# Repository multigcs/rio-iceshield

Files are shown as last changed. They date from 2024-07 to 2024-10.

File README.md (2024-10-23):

# rio-iceshield
6 Axis LinuxCNC-RIO Raspberry-PI FPGA-Hat - kicad project

**experimental**

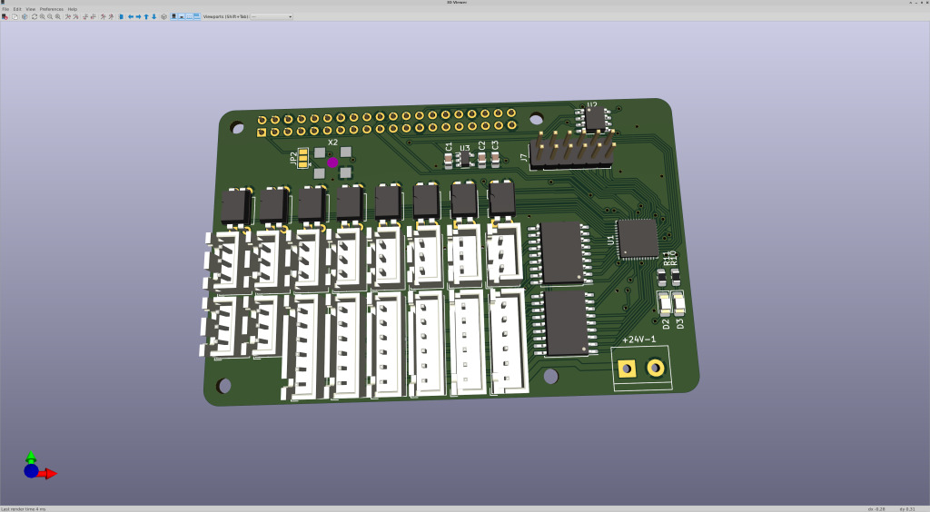
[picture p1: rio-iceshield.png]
rio-iceshield


## software / gateware
https://github.com/multigcs/riocore

## BOM

## Forum
German: https://www.cnc-aus-holz.at/index.php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
English: https://forum.linuxcnc.org/18-computer/49142-linuxcnc-rio-realtimeio-for-linuxcnc-based-on-fpga-ice40-ecp5

## to provide a clock signal for the FPGA
```
gpio mode 7 clock
gpio clock 7 5000000
```

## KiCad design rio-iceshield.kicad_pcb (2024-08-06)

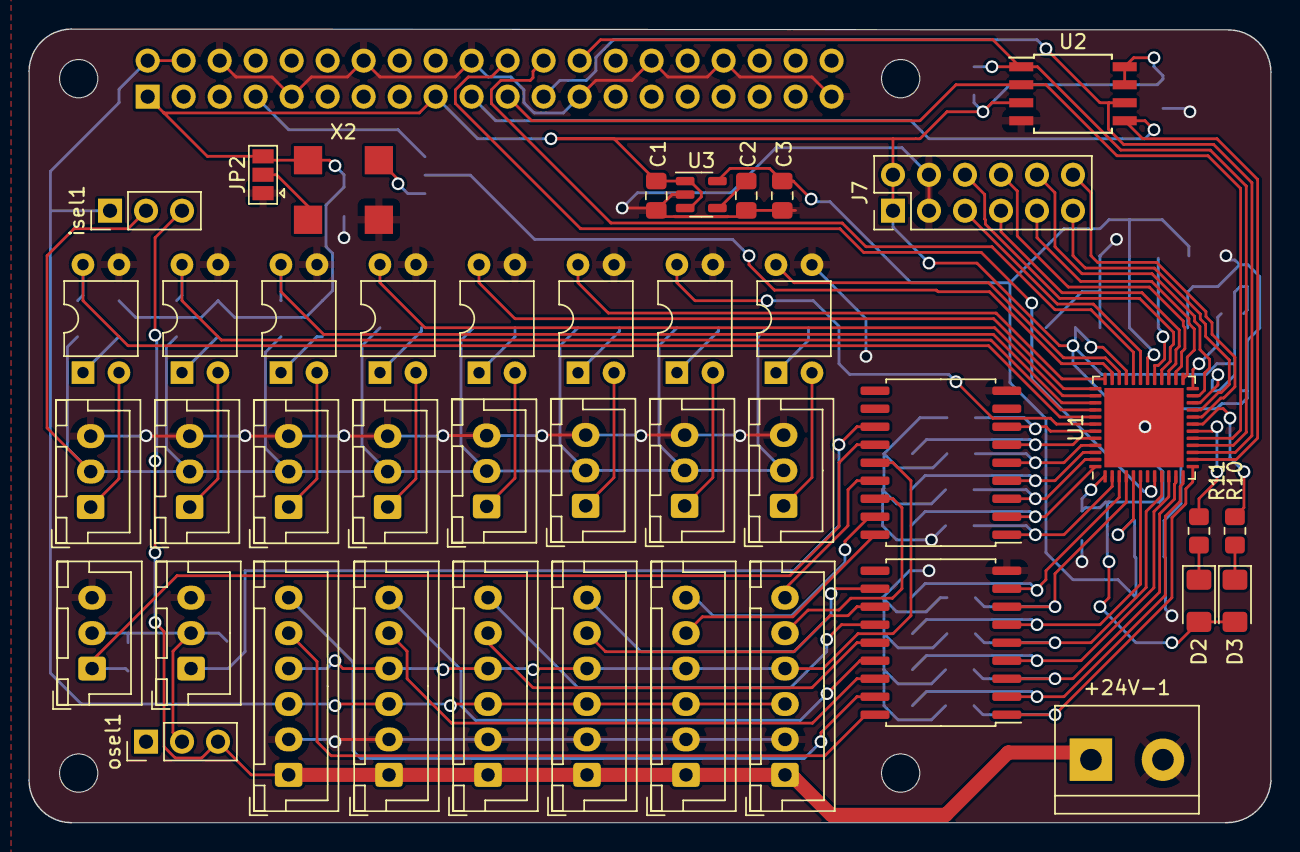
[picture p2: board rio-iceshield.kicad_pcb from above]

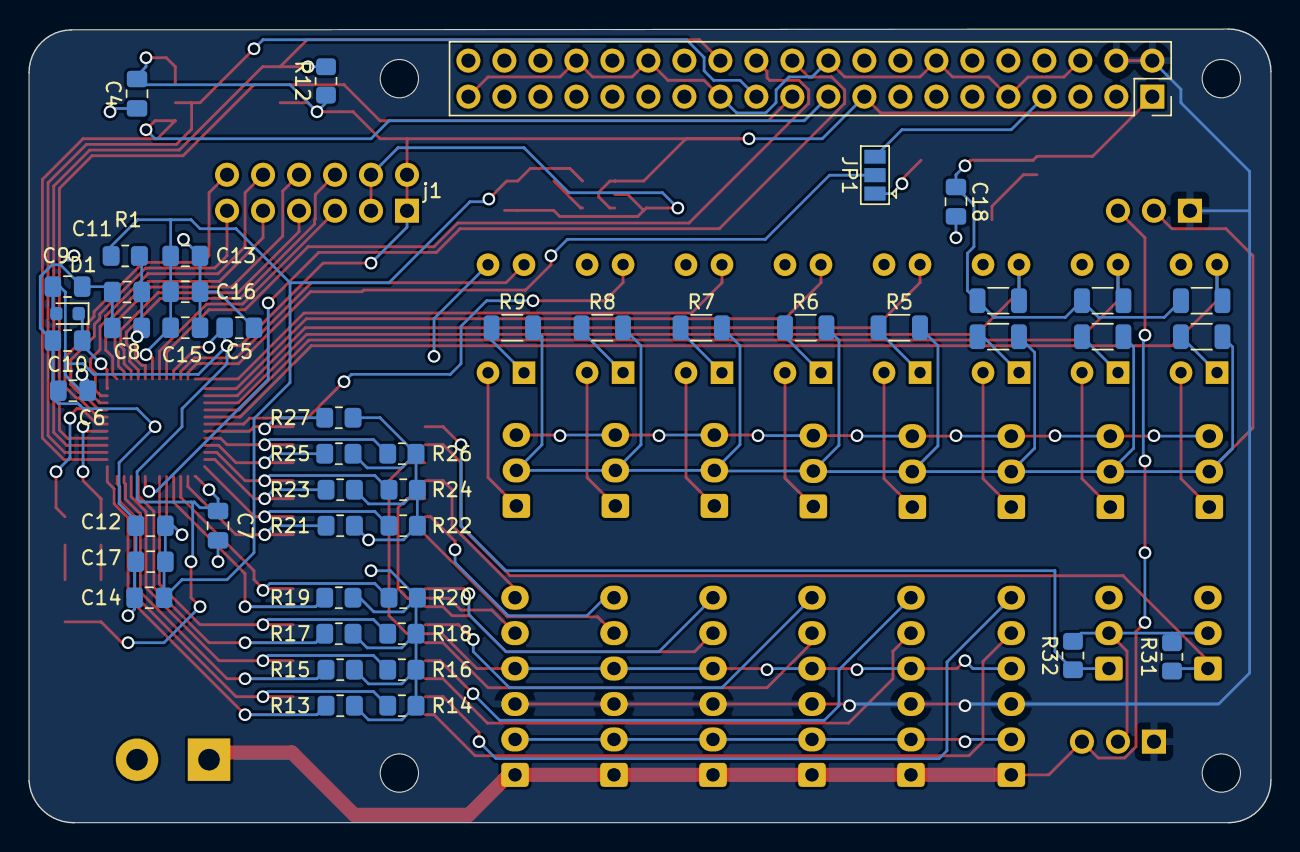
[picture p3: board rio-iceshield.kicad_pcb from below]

Board: 2 copper layers, 87.6 x 56.0 mm, 94 parts (48 on the bottom side), 86 nets.

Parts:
+24V-1: Screw_Terminal_01x02; TerminalBlock_bornier-2_P5.08mm
C1, C3: 4u7; C_0805_2012Metric_Pad1.18x1.45mm_HandSolder
C2, C13, C17: 10n; C_0805_2012Metric_Pad1.18x1.45mm_HandSolder
C4, C5, C6, C7, C8, C9, C10, C14, C16, C18: 100n; C_0805_2012Metric_Pad1.18x1.45mm_HandSolder
C11: 10u; C_0805_2012Metric_Pad1.18x1.45mm_HandSolder
C12, C15: 1u; C_0805_2012Metric_Pad1.18x1.45mm_HandSolder
D1: 1N 4148WT7 DII; D_0603_1608Metric
D2, D3: LED; LED_1206_3216Metric_Pad1.42x1.75mm_HandSolder
J2, J3, J4, J5, J6: Conn_01x06; JST_XH_B6B-XH-A_1x06_P2.50mm_Vertical
J7: Conn_02x06_Odd_Even; PinHeader_2x06_P2.54mm_Vertical
JP1, JP2: SolderJumper_3_Open; SolderJumper-3_P1.3mm_Open_Pad1.0x1.5mm
Jo1: Conn_01x06; JST_XH_B6B-XH-A_1x06_P2.50mm_Vertical
MH1, MH2, MH3, MH4: MountingHole_2.7mm_M2.5
R1: 100; R_0805_2012Metric_Pad1.20x1.40mm_HandSolder
R2, R3, R4, R5, R6, R7, R8, R9: 3K3; R_1206_3216Metric
R10, R11: 900; R_0805_2012Metric_Pad1.20x1.40mm_HandSolder
R12: 10k; R_0805_2012Metric_Pad1.20x1.40mm_HandSolder
R13, R14, R15, R16, R17, R18, R19, R20, R21, R22, R23, R24, R25, R26, R27: 20k; R_0805_2012Metric_Pad1.20x1.40mm_HandSolder
R28, R29, R30: 20K; R_1206_3216Metric
R31, R32: 3k3; R_0805_2012Metric_Pad1.20x1.40mm_HandSolder
U1: ICE40UP5K-SG48ITR; QFN-48-1EP_7x7mm_P0.5mm_EP5.6x5.6mm
U2: AT25SF041B-SHD 4 Mb; SOIC-8W_5.3x5.3mm_P1.27mm
U3: LD3985M122R_SOT23; SOT-23-5
U4, U5: ULN2803A; SOIC-18W_7.5x11.6mm_P1.27mm
U7, U8, U9, U10, U11, U12, U13, U14: PC817; DIP-4_W7.62mm
X2: XO91; Oscillator_SMD_EuroQuartz_XO91-4Pin_7.0x5.0mm
input1, input2, input3, input4, input5, input6, input7, input8: Conn_01x03; JST_XH_B3B-XH-A_1x03_P2.50mm_Vertical
isel1: Conn_01x03; PinHeader_1x03_P2.54mm_Vertical
j1: GPIO; PinSocket_2x20_P2.54mm_Vertical
osel1: Conn_01x03; PinHeader_1x03_P2.54mm_Vertical
output1, output2: Conn_01x03; JST_XH_B3B-XH-A_1x03_P2.50mm_Vertical

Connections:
1v2: C3.1, C12.1, C13.1, C14.1, C15.1, C16.1, C17.1, R1.1, U1.5 (VCC), U1.30 (VCC), U3.5 (VOUT)
2: R21.2, U1.2 (IOB_6a), U5.1 (I1)
2v5: C10.1, D1.1 (K), U1.24 (VPP_2V5)
3: R20.2, U1.3 (IOB_9b), U4.8 (I8)
3v3: C1.1, C4.2, C5.2, C6.2, C7.2, C9.1, C18.1, D1.2 (A), D2.2 (A), D3.2 (A), J7.1, J7.2, JP2.3 (B), R12.1, R28.1, R29.1, R30.1, U1.1 (VCCIO_2), U1.22 (SPI_VCCIO1), U1.33 (VCCIO_0), U2.3 (~WP/IO2), U2.7 (~HOLD/IO3), U2.8 (VCC), U3.1 (VIN), U3.3 (INH), X2.4 (V+), j1.1, j1.17
4: R19.2, U1.4 (IOB_8a), U4.7 (I7)
5v: J2.3, J3.3, J4.3, J5.3, J6.3, Jo1.3, isel1.1, j1.2, j1.4, osel1.1
6: R18.2, U1.6 (IOB_13b), U4.6 (I6)
9: R17.2, U1.9 (IOB_16a), U4.5 (I5)
10: R16.2, U1.10 (IOB_18a), U4.4 (I4)
11: R15.2, U1.11 (IOB_20a), U4.3 (I3)
12: R14.2, U1.12 (IOB_22a), U4.2 (I2)
12v: +24V-1.1, J2.1, J3.1, J4.1, J5.1, J6.1, Jo1.1, isel1.3, osel1.3
13: R13.2, U1.13 (IOB_24a), U4.1 (I1)
18: R11.1, U1.18 (IOB_31b)
19: R10.1, U1.19 (IOB_29b)
20: J7.12, U1.20 (IOB_25b_G3)
21: J7.11, U1.21 (IOB_23b)
23: J7.10, U1.23 (IOT_37a)
25: J7.9, U1.25 (IOT_36b)
26: J7.8, U1.26 (IOT_39a)
27: J7.7, U1.27 (IOT_38b)
28: J7.6, U1.28 (IOT_41a)
31: J7.5, U1.31 (IOT_42b)
32: U1.32 (IOT_43a), j1.24
34: U1.34 (IOT_44b), U14.4
35: JP1.2 (C), U1.35 (IOT_46b_G0)
36: U1.36 (IOT_48b), U12.4
37: U1.37 (IOT_45a_G1), U11.4
38: U1.38 (IOT_50b), U10.4
39: R28.2, U1.39 (RGB0), U9.4
40: R29.2, U1.40 (RGB1), U8.4
41: R30.2, U1.41 (RGB2), U7.4
42: U1.42 (IOT_51a), U13.4
43: R27.2, U1.43 (IOT_49a), U5.7 (I7)
44: R26.2, U1.44 (IOB_3b_G6), U5.6 (I6)
45: R25.2, U1.45 (IOB_5b), U5.5 (I5)
46: R24.2, U1.46 (IOB_0a), U5.4 (I4)
47: R23.2, U1.47 (IOB_2a), U5.3 (I3)
48: R22.2, U1.48 (IOB_4a), U5.2 (I2)
CRESET: U1.8 (~CRESET), j1.22
unnamed: D2.1 (K), R11.2
unnamed: D3.1 (K), R10.2
unnamed: JP1.1 (A), X2.3 (OUT)
unnamed: JP2.2 (C), X2.1 (EN)
unnamed: R2.1, U7.1
unnamed: R3.1, U8.1
unnamed: R4.1, U9.1
unnamed: R5.1, U10.1
unnamed: R6.1, U11.1
unnamed: R7.1, U12.1
unnamed: R8.1, U13.1
unnamed: R9.1, U14.1
unnamed: C8.1, C11.1, R1.2, U1.29 (VCCPLL)
unnamed: C2.1, U3.4 (BYP)
unnamed: U7.2, input1.1
unnamed: U8.2, input2.1
unnamed: U9.2, input3.1
unnamed: U10.2, input4.1
unnamed: U11.2, input5.1
unnamed: U12.2, input6.1
unnamed: U13.2, input7.1
unnamed: U14.2, input8.1
RPI_CLK: JP1.3 (B), j1.7
SPI_CS1: R12.2, U1.16 (IOB_35b_SPI_SS), U2.1 (~CS), j1.26
SPI_MISO: U1.17 (IOB_33b_SPI_SI), U2.2 (SO/IO1), j1.21
SPI_MOSI: U1.14 (IOB_32a_SPI_SO), U2.5 (SI/IO0), j1.19
SPI_SCK: U1.15 (IOB_34a_SPI_SCK), U2.6 (SCK), j1.23
enable: J2.4, J3.4, J4.4, J5.4, J6.4, Jo1.4, U5.14 (O5)
gnd: +24V-1.2, C1.2, C2.2, C3.2, C4.1, C5.1, C6.1, C7.1, C8.2, C9.2, C10.2, C11.2, C12.2, C13.2, C14.2, C15.2, C16.2, C17.2, C18.2, J2.2, J3.2, J4.2, J5.2, J6.2, J7.3, J7.4, JP2.1 (A), Jo1.2, R13.1, R14.1, R15.1, R16.1, R17.1, R18.1, R19.1, R20.1, R21.1, R22.1, R23.1, R24.1, R25.1, R26.1, R27.1, U1.49 (GND), U2.4 (GND), U3.2 (GND), U4.9 (GND), U5.9 (GND), U7.3, U8.3, U9.3, U10.3, U11.3, U12.3, U13.3, U14.3, X2.2 (GND), input1.3, input2.3, input3.3, input4.3, input5.3, input6.3, input7.3, input8.3, j1.6, j1.9, j1.14, j1.20, j1.25, j1.30, j1.34, j1.39, output1.3, output2.3
in_power: R2.2, R3.2, R4.2, R5.2, R6.2, R7.2, R8.2, R9.2, input1.2, input2.2, input3.2, input4.2, input5.2, input6.2, input7.2, input8.2, isel1.2
j1_dir: Jo1.6, U4.17 (O2)
j1_step: Jo1.5, U4.18 (O1)
j2_dir: J2.6, U4.15 (O4)
j2_step: J2.5, U4.16 (O3)
j3_dir: J3.6, U4.13 (O6)
j3_step: J3.5, U4.14 (O5)
j4_dir: J4.6, U4.11 (O8)
j4_step: J4.5, U4.12 (O7)
j5_dir: J5.6, U5.17 (O2)
j5_step: J5.5, U5.18 (O1)
j6_dir: J6.6, U5.15 (O4)
j6_step: J6.5, U5.16 (O3)
out1: R31.1, U5.13 (O6), output1.1
out2: R32.1, U5.12 (O7), output2.1
out_power: R31.2, R32.2, osel1.2, output1.2, output2.2

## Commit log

2024-07-03 initial release
    [input.kicad_sch, rio-iceshield.kicad_pcb, rio-iceshield.kicad_sch]
2024-07-07 adding missing in/out powerlines
    [input.kicad_sch, rio-iceshield.kicad_pcb, rio-iceshield.kicad_sch]
2024-08-06 replacing spi-flash package
    [rio-iceshield.kicad_pcb, rio-iceshield.kicad_sch]
2024-08-06 adding pulldowns to outputs / fixing uln gnd's
    [rio-iceshield.kicad_pcb, rio-iceshield.kicad_sch]
2024-08-06 other diode (i used in on my test-board)
    [rio-iceshield.kicad_sch]
2024-08-06 adding pullups to in1-3
    [input.kicad_sch, rio-iceshield.kicad_pcb, rio-iceshield.kicad_sch]
2024-08-06 adding pullups to out1-2
    [rio-iceshield.kicad_pcb, rio-iceshield.kicad_sch]
